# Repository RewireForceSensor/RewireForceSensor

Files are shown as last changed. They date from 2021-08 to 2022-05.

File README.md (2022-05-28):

# RewireForceSensor
A project for the Rewire Robotics Laboratory at UT Austin. Contains Android Studio code for our custom app as well as Arduino code for both iterations of the footplate and the PCB design for the Load Cell version of the footplate.

Built with Dr. James Sulzer by undergraduate students Timothy Pollard-Grayson, Corbin Capo, and Ishan Deshpande

Special thanks to Trey Crisco

# Project Description
Footplate designed for a patient in a medical stander, in order to monitor foot and pressure information. Uses bluetooth to communicate to an app where a physical
therapist can actively and passively keep track of the patient's progress.

# Relevant Links
[App Releases](https://github.com/RewireForceSensor/RewireForceSensor/releases)

[Atlantic Article](https://www.theatlantic.com/magazine/archive/2021/11/engineers-daughter-tbi-rehab/620172/)

[UT Engineering Article](https://cockrell.utexas.edu/news/archive/9435-a-personal-experience-galvanizes-rehab-tech-researchers)

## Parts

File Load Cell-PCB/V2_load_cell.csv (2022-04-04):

Id | Designator | Package | Quantity | Designation | Link
1 | SW1 | PinSocket_1x02_P2.54mm_Vertical | 1 | SW_DIP_x01 | https://www.amazon.com/COOLOOdirect-Solder-Rocker-Switch-Toggle/dp/B071Y7SMVQ
2 | D1 | PinSocket_1x02_P2.54mm_Vertical | 1 | LED
3 | A1 | Arduino_Nano | 1 | Arduino_Nano_Every | https://www.amazon.com/ELEGOO-Arduino-ATmega328P-Without-Compatible/dp/B0713XK923
4 | J9,J8,J6,J7 | JST_PH_B3B-PH-K_1x03_P2.00mm_Vertical | 4 | Conn_01x03 | https://www.amazon.com/DEPEPE-2-54mm-Headers-Arduino-Prototype/dp/B074HVBTZ4
5 | H4,H3,H2,H1 | MountingHole_3.2mm_M3 | 4 | MountingHole
6 | J16,J10,J12,J14 | PinHeader_1x06_P2.54mm_Vertical | 4 | Conn_01x06
7 | R12,R11 | R_Axial_DIN0207_L6.3mm_D2.5mm_P7.62mm_Horizontal | 2 | 2k
8 | R10,R9,R1,R2,R3,R4,R5,R6,R7,R8 | R_Axial_DIN0207_L6.3mm_D2.5mm_P7.62mm_Horizontal | 10 | 1k
9 | J1 | PinSocket_1x02_P2.54mm_Vertical | 1 | Conn_01x02
10 | J2,J3 | PinSocket_1x06_P2.54mm_Horizontal | 2 | Conn_01x06
11 | J11,J13,J15,J17 | PinHeader_1x04_P2.54mm_Vertical | 4 | Conn_01x04

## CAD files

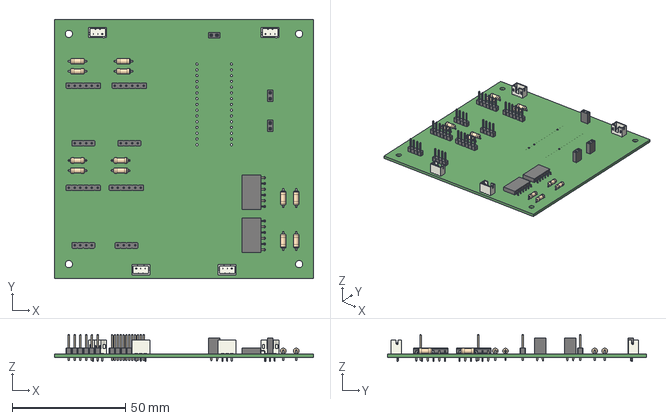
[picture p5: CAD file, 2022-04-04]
Load Cell-PCB/V2_load_cell.step
114.3 x 114.3 x 11.9 mm

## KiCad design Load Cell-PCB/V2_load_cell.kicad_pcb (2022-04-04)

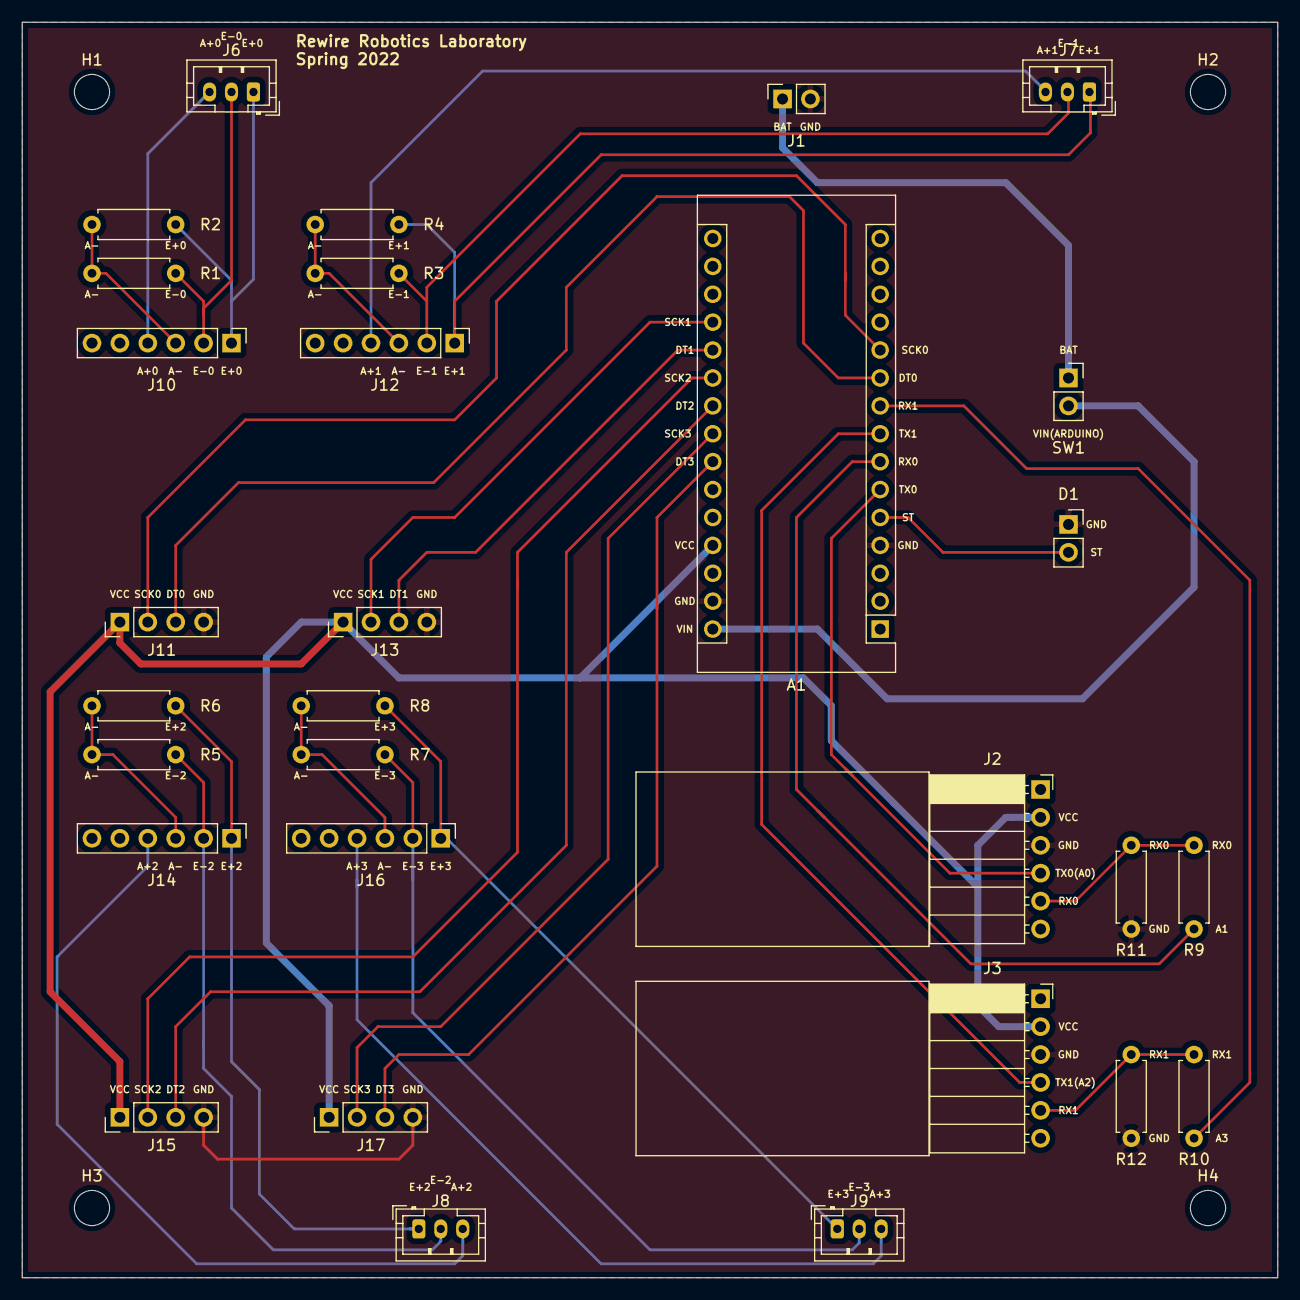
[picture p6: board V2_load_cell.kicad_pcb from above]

Board: 2 copper layers, 114.3 x 114.3 mm, 34 parts (0 on the bottom side), 35 nets.

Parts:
A1: Arduino_Nano_Every; Arduino_Nano
D1: LED; PinSocket_1x02_P2.54mm_Vertical
H1, H2, H3, H4: MountingHole; MountingHole_3.2mm_M3
J1: Conn_01x02; PinSocket_1x02_P2.54mm_Vertical
J2, J3: Conn_01x06; PinSocket_1x06_P2.54mm_Horizontal
J6, J7, J8, J9: Conn_01x03; JST_PH_B3B-PH-K_1x03_P2.00mm_Vertical
J10, J12, J14, J16: Conn_01x06; PinHeader_1x06_P2.54mm_Vertical
J11, J13, J15, J17: Conn_01x04; PinHeader_1x04_P2.54mm_Vertical
R1, R2, R3, R4, R5, R6, R7, R8, R9, R10: 1k; R_Axial_DIN0207_L6.3mm_D2.5mm_P7.62mm_Horizontal
R11, R12: 2k; R_Axial_DIN0207_L6.3mm_D2.5mm_P7.62mm_Horizontal
SW1: SW_DIP_x01; PinSocket_1x02_P2.54mm_Vertical

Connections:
/A+0: J6.3, J10.4
/A+1: J7.3, J12.4
/A+2: J8.3, J14.4
/A+3: J9.3, J16.4
/DT0: A1.10, J11.3
/DT1: A1.20, J13.3
/DT2: A1.22, J15.3
/DT3: A1.24, J17.3
/E+0: J6.1, J10.1, R2.2
/E+1: J7.1, J12.1, R4.2
/E+2: J8.1, J14.1, R6.2
/E+3: J9.1, J16.1, R8.2
/E-0: J6.2, J10.2, R1.2
/E-1: J7.2, J12.2, R3.2
/E-2: J8.2, J14.2, R5.2
/E-3: J9.2, J16.2, R7.2
/RX0: A1.7, R9.2
/RX0R: J2.5, R9.1, R11.1
/RX1: A1.9, R10.2
/RX1R: J3.5, R10.1, R12.2
/SCK0: A1.11, J11.2
/SCK1: A1.19, J13.2
/SCK2: A1.21, J15.2
/SCK3: A1.23, J17.2
/ST: A1.5, D1.2
/Sheet61D3CBFB/A-: J10.3, R1.1, R2.1
/TX0: A1.6, J2.4
/TX1: A1.8, J3.4
/VIN: A1.30, SW1.2
/sheet61D4E250/A-: J12.3, R3.1, R4.1
/sheet61D4EE5D/A-: J14.3, R5.1, R6.1
/sheet61D4FC90/A-: J16.3, R7.1, R8.1
BAT: J1.1, SW1.1
GND: A1.4, A1.29, D1.1, J1.2, J2.3, J3.3, J11.4, J13.4, J15.4, J17.4, R11.2, R12.1
VCC: A1.27, J2.2, J3.2, J11.1, J13.1, J15.1, J17.1

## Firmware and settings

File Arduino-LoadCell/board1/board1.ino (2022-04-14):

#include <Chrono.h>
#include <SoftwareSerial.h>
#include "HX711.h"

#define BT1TX 3
#define BT1RX 4
#define BT2TX 5
#define BT2RX 6
#define LC1_DOUT_PIN  7
#define LC1_SCK_PIN  8
#define LC2_DOUT_PIN  A1
#define LC2_SCK_PIN  A0
#define LC3_DOUT_PIN  A3
#define LC3_SCK_PIN  A2
#define LC4_DOUT_PIN  A5
#define LC4_SCK_PIN  A4

Chrono timer;

HX711 scales[4];
int factors[4];

long offsets[4];
float xdist[4] = {-1.3, 1.3, -1.3, 1.3};
float ydist[4] = {2.85, 2.85, -2.85, -2.85};
float dist = 3.11;

float copx = 0;
float copy = 0;
float valsum = 0;

SoftwareSerial BT1Serial(BT1TX, BT1RX);
SoftwareSerial BT2Serial(BT2TX, BT2RX);

char c = '\n';
String s = "";

int times = 50;

void setup() {
  // put your setup code here, to run once:
  Serial.begin(9600);
  BT1Serial.begin(9600);
  BT2Serial.begin(9600);

  scales[0].begin(LC1_DOUT_PIN, LC1_SCK_PIN);
  scales[1].begin(LC2_DOUT_PIN, LC2_SCK_PIN);
  scales[2].begin(LC3_DOUT_PIN, LC3_SCK_PIN);
  scales[3].begin(LC4_DOUT_PIN, LC4_SCK_PIN);

  factors[0] = 1;
  factors[1] = 1;
  factors[2] = 1;
  factors[3] = 1;
  
  offsets[0] = 0;
  offsets[1] = 0;
  offsets[2] = 0;
  offsets[3] = 0;
  
  for(int i=0; i<4; i++){
    //long zero_factor = scales[i].read_average(times); //Get a baseline reading
    //Serial.print("Zero factor: "); //This can be used to remove the need to tare the scale. Useful in permanent scale projects.
    //Serial.println(zero_factor);
    //offsets[i] = zero_factor;
    
    scales[i].set_scale(1);
    scales[i].set_offset(0);
    scales[i].tare();
  }
}

void loop() {
  // Keep reading from HC-06 and send to Arduino Serial Monitor
  /*BT2Serial.listen();
  if (BT2Serial.available())
  {
      c = BT2Serial.read();
      s += c;
      
      if(c == '\n'){
        s.remove(s.length()-1); // remove newline
        s.remove(s.length()-1); // remove cr
      */
      if(timer.hasPassed(200)){
        for(int i=0; i<4; i++){
          s += "0.00,";  
        }
        for(int i=0; i<4; i++){
          float val = scales[i].get_units();
          s += val;
          //s += random(0, 1000)/100.0f;
          s += ",";
          valsum += val;
          copx += val*xdist[i];
          copy += val*ydist[i];
        }

        copx /= valsum;
        copy /= valsum;

        s += copx;
        s += ",";
        s += copy;
        s += ",";

        copx = 0;
        copy = 0;
        valsum = 0;
        
        BT1Serial.println(s);
        Serial.println(s);
        s="";
        c=' ';
        timer.restart();
      }
      //}
    
  //}  
}

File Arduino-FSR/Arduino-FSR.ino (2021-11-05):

#include <Chrono.h>
#include <SoftwareSerial.h>

SoftwareSerial BTSerial (2,3);

Chrono timer;

//float cf = 19.5*2.20462*5/12.5;
int ffsdata = 0;
float vout;

int ports[6] = {A0, A1, A2, A3, A4, A5};
float values[6];
float coeffs[6] = {15, 15, 15, 15, 15, 15};
float threshold = 0.03;

void setup() {
  // put your setup code here, to run once:
  Serial.begin(9600);
  BTSerial.begin(9600);
}

void loop() {
  // put your main code here, to run repeatedly:
  if(timer.hasPassed(100)){
    for(int i=0; i<6; i++){
      ffsdata = analogRead(ports[i]);
      vout = (ffsdata * 5.0) / 1023.0;
      vout = (vout > threshold)?(vout * coeffs[i]):0.0;
      values[i] = vout;
      
      Serial.print(i);
      Serial.print(": ");
      Serial.println(values[i], 3);

      BTSerial.print(values[i], 3);
      BTSerial.print(",");
    }

    BTSerial.println();

    timer.restart();
    
    
    /*Serial.print(analogRead(A0));
    Serial.print(',');
    Serial.print(analogRead(A1));
    Serial.print(',');
    Serial.print(analogRead(A2));
    //Serial.print(',');
    //Serial.print(analogRead(A3));
    Serial.print(',');
    Serial.print(analogRead(A4));
    Serial.print(',');
    Serial.print(analogRead(A5));
    Serial.println();
    
    
    BTSerial.print(analogRead(A0));
    BTSerial.print(',');
    BTSerial.print(analogRead(A1));
    BTSerial.print(',');
    BTSerial.print(analogRead(A2));
    //BTSerial.print(',');
    //BTSerial.print(analogRead(A3));
    BTSerial.print(',');
    BTSerial.print(analogRead(A4));
    BTSerial.print(',');
    BTSerial.print(analogRead(A5));
    BTSerial.println();
    timer.restart();*/

    
  }
}

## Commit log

2021-07-30 Code reorganized and new android app, arduino file added
2021-08-03 Added heatmap library
2021-08-06 removed obsolete android app, got app working with 6 sensors and calibrated force sensors to give more accurate readings
2021-08-17 File creation and logging works, yet to be tested with logging data points and currently exports into Downloads/RewireForceSensor/
2021-08-19 File creation and writing has been switched to the storage access framework, everything works. Connect button disables when connected and log button does not work when disconnected.
2021-09-23 wrote better three-point moving average code and better sensor data array format (now stored in integers instead of strings)
2021-09-24 changed int[] to double[] for storage of sensor data (comes from arduino as a double)
2021-09-30 added buttons, infinite scroll does not look good (yet)
2021-10-03 scrolling now operates on buttons only, title changes when you scroll, and infinite scrolling is enabled.
2021-10-04 fixed x-axis graphing issue
2021-10-04 added disconnect button, with clearing of fragments and logging support
2021-10-04 changed size of disconnect button
2021-11-05 small bugfixes for 11-7 test session with livvie
    [Arduino-FSR.ino]
2022-04-04 Rfs 52 (#20)
    * Successfully created a new fragment and boolean for the load cell in which we can draw custom things. Sizing of view inside LoadCellFragment needs to be fixed.
    * Fixing some fragment view things
    * Fixed some fragment view things
    * view stuff
    * initial commit of pcb v1
    * 2-17-22
    * pcb v2 update
    * JST connectors, increased track width of VCC, moved bluetooth modules, other small fixes
    * commit
    * I have no idea what is going on
    * v2
    * Changes:
    - Moved mounting holes
    - Changed size of HC-05 footprint marker
    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
    [V2_load_cell-B_Cu.gbl, V2_load_cell-B_Cu.gbr, V2_load_cell-B_Mask.gbr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]
2022-04-11 Number Format Exception Handled (#22)
    * Added catch for NumberFormatException, when arduino sometimes skips numbers/doesn't transfer correctly. Also fixed connectStatus to display correct info.
    * Added log message on number format error; fixed disconnect text overflow
2022-04-14 Rfs 59 (#23)
    * merged in arduino-loadcell changes
    * Lots of progress on calibration routine
    * calibration routine finished
    * fixed some stuff
    * fixed some more stuff
    [V2_load_cell-B_Cu.gbl, V2_load_cell-B_Cu.gbr, V2_load_cell-B_Mask.gbr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]
2022-04-18 Add center of pressure (#24)
    * added progress bar
    * made significant progress on center of pressure. conversion to absolute coordinates is still crappy because of the clamping, but it works OK ish
    * worked on fixing COP
    * added floor so that data cannot go below 0.
2022-04-18 fixed clamping of cop dot to not go past edges of load cell on screen, and fixed what to do when app receives bad data (#25)
